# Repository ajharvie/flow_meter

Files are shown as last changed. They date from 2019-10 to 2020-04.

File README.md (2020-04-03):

**Optical Determination of Flow-rate and Flow-Uniformity in Segmented Flows**

This repository contains firmware and design files required to implement a flow meter described in Chemical Engineering Journal. 

The paper can be found here: https://doi.org/10.1016/j.cej.2020.124908

The paper's supporting information contains intructions on assembly, programming and calibration.

*Andrew J. Harvie & John C. de Mello*

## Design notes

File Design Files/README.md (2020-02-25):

Design files for various flow meter parts, including:
1) .stl and .step files for the 3D-printed block.
2) Eagle (.brd) format design for PCB used for mounting OPT101s. This design is slightly updated from the version photographed in the paper (it's smaller).
3) Circuit diagram for device and drawing of block dimensions.

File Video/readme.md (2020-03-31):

Videos of the flow meter in action. Extended captions and information on the videos are included in the paper and its supporting information, but in brief:
1) SI1.mp4 shows footage of the flow stream and measured **Q** value vs time for a flow containing two discrete defects, in a segmented flow of (dyed) DCM and water.
2) SI2.mp4 shows similar data to SI1.mp4 but for a constantly disordered flow.
3) SI3.mp4 shows application of the sensor to quality control. The sensor is mounted in a black opaque box to the left, and switches a two-position valve between "discard" and "collect" positions depending on flow uniformity. The model "reaction" is the mixing of blue- and orange-dyed DCM in a segmented flow with water, to make lovely brown-coloured slugs. Deviations from uniformity result in uneven mixing of dyes, and a change in the colour of the resulting slugs.

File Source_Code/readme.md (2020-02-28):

Source code for the flow meter. Three versions are provided:
1) Flow_Meter_Deprecated.ino is the version used to generate the data shown in the paper, using a teensy 3.6. It is written for a now-obsolete version of teensyduino (v1.39) and should not be used.
2) FlowMeterUPDATED.ino is updated for the current (Feb 2020) version of teensyduino (v1.51). There are a few changes, specifically removal of a few functions related to the ADC library. All settings are otherwise the same. It is compatible with both Teensy 3.6 and 4.0.
3) FlowMeterHighRate.ino is updated for the capability of the new Teensy 4.0 board - the sample rate has been increased 10x, and the number of samples considered in the calculation has been increased 2.5x. This allows for accurate measurement of much higher flow rates. It will not work correctly on the Teensy 3.6.

The file "FlowMeterSignals.ino" contains code for reading the raw optical signals from the flow meter's detectors.

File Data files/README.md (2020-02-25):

Raw data for plots shown in paper.

"Calibration_Data.csv" contains raw signals used to produce figure 5.

"QC_data.csv" contains data recorded during acquisition of video S3 (not shown in paper)

"Q_traces.csv" contains the raw data plotted in figs 6 & 7.

"Ramping_Data.csv" contains the data plotted in fig 9. 

"Signals.csv" contains raw optical signals in figures 3 & 4. 

"TubesPhotograph.png" is a (white balance corrected) photograph of three tubes, which was cropped to obtain the images in figures 10d and 10f. The left-most tube is the result of a control experiment where no xanthate was added, and was not included in the paper's results. The middle and right-hand tubes are shown in figures 10d and 10f respectively.

"DropletImagesBlue.jpg" is the (blue channel monochrome) image from which figures 10c and 10e were cropped, where "DropletImageRaw.jpg" contains the unprocessed raw images (presented as a mosaic in one file).

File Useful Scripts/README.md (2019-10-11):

Some MATLAB scripts used for producing plots, and simulating the flow meter. 
1) "DFT_Signals_Fig4.m", was used to produce figure 4 in the main paper. 
2) "FFT_vs_SDFT.m" produces figure S1. It requires "sdft_plug.m" to work. 
3) "Signal_Generator.m" was used to produce the simulated signals from the supporting information.
4) "Simulator.m" does what it says on the tin - use the signals generated with "Signal_Generator.m". The first 1500 output samples (consistent with the first 15s, or the first full sDFT window) are not output, as these are related to the initial "filling" of the sDFT.

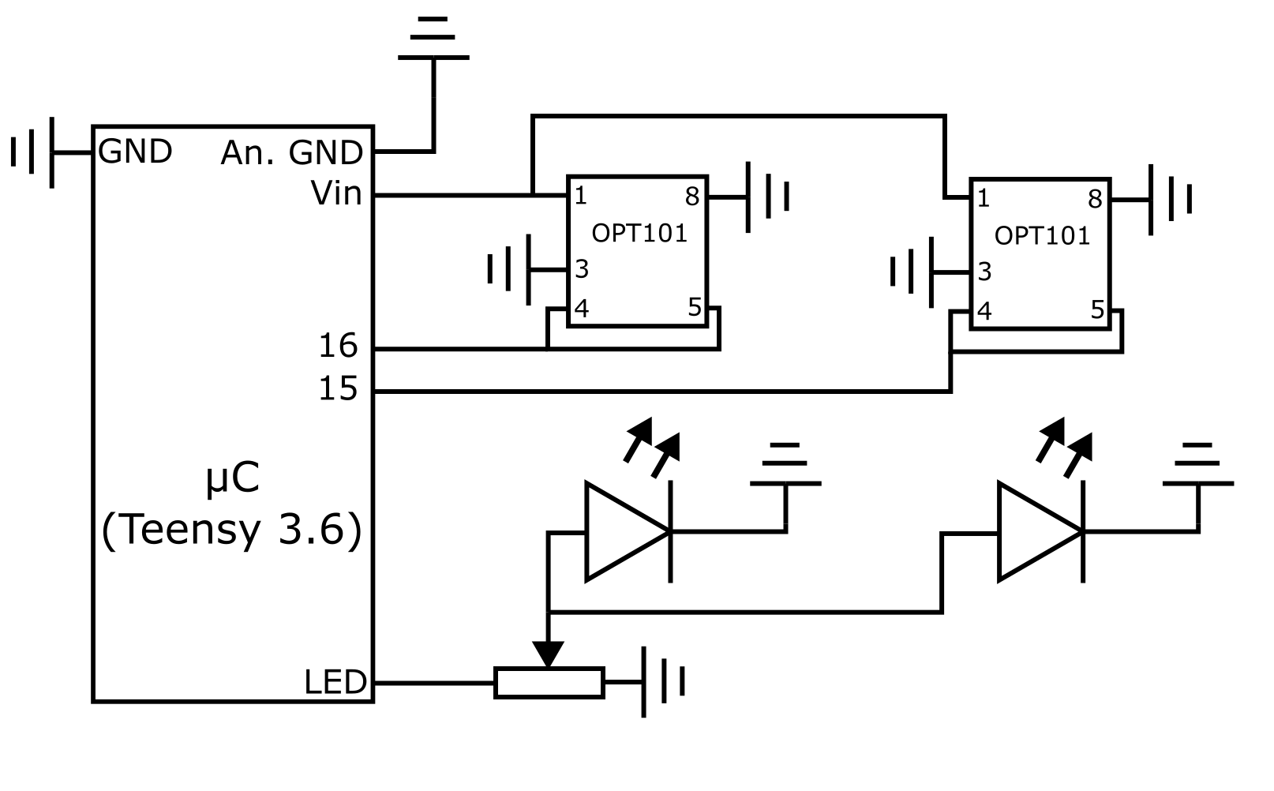
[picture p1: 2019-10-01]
Design Files/circuit_diagram.png

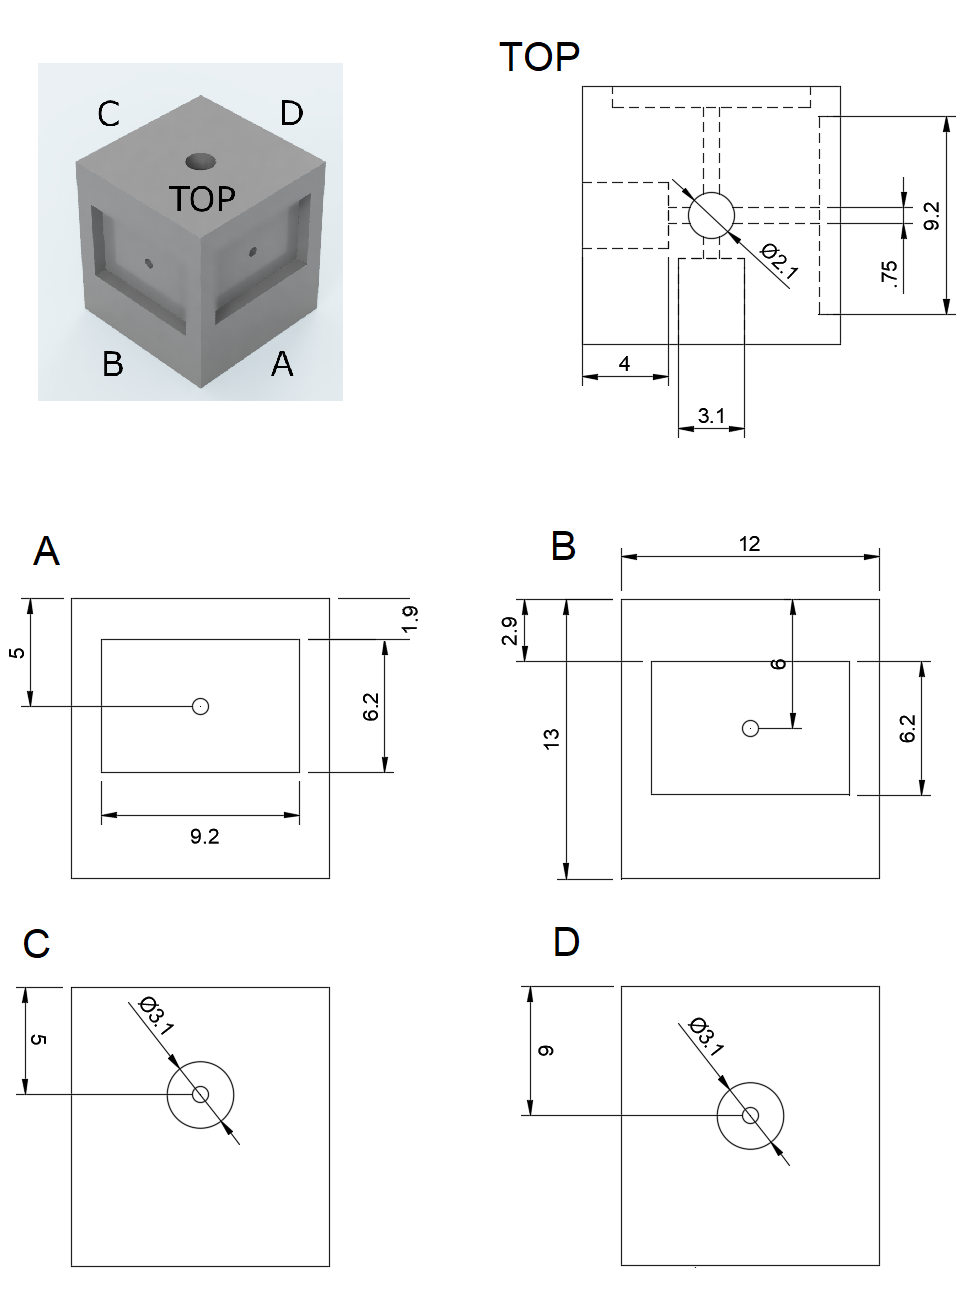
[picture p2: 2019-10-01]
Design Files/technical_drawing.png

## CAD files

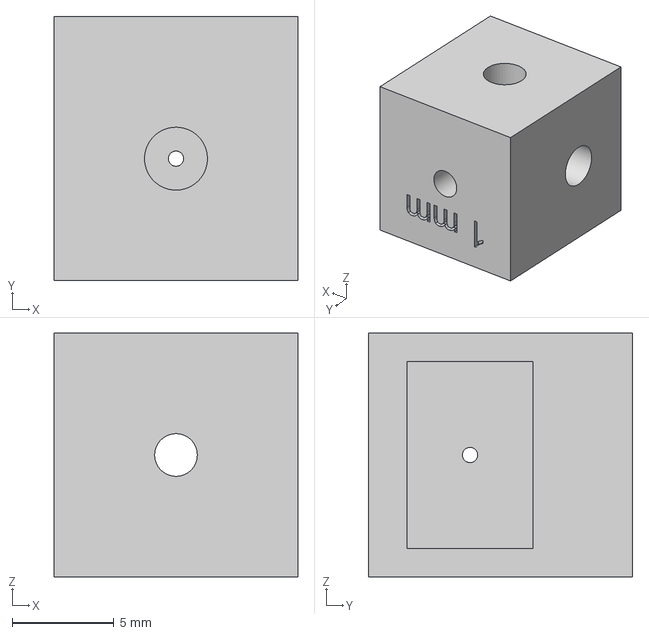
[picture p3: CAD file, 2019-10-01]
Design Files/LED_block_1mm.step
12.0 x 13.0 x 12.0 mm

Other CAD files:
Design Files/LED_block_1mm.stl

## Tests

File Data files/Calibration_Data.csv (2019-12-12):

time | 100 | F | v | Q | 50 | F | v | Q | 15 |  |  |  | 25 | F | v | Q | 300 | F | v | Q | 600 | F | v | Q | 800 | F | v | Q | 1000 | F | v | Q
0 |  | 104.17 | 2.1976 | -0.021 |  | 50 | 1.0549 | 0.0018 |  | 15.07 | 0.3178 | -0.0223 |  | 26.06 | 0.5497 | 0.1012 |  | 304.44 | 6.4227 | -0.001 |  | 616.47 | 13.0057 | 0.003 |  | 803.29 | 16.9471 | -0.0067 |  | 1014.5 | 21.403 | -0.005
1.5 |  | 104.62 | 2.2073 | -0.0056 |  | 50.55 | 1.0664 | 0.0066 |  | 14.44 | 0.3047 | 0.0134 |  | 27.02 | 0.5701 | 0.0569 |  | 304.31 | 6.42 | 0.0167 |  | 616.9 | 13.0147 | 0.0093 |  | 806.02 | 17.0046 | 0.0005 |  | 1011.78 | 21.3456 | 0.0031
3 |  | 104.8 | 2.2109 | 0.0012 |  | 50.68 | 1.0693 | 0.0026 |  | 14.44 | 0.3047 | -0.0123 |  | 27.46 | 0.5794 | -0.037 |  | 304.97 | 6.4339 | 0.0222 |  | 617.97 | 13.0374 | 0.0059 |  | 805.92 | 17.0025 | 0.0084 |  | 1007.79 | 21.2613 | 0.0078
4.5 |  | 103.76 | 2.1891 | 0.0031 |  | 50.39 | 1.0631 | -0.0043 |  | 15.95 | 0.3366 | -0.0842 |  | 27.69 | 0.5842 | 0.0158 |  | 307.64 | 6.4902 | 0.0183 |  | 619.5 | 13.0696 | -0.004 |  | 806.76 | 17.0203 | 0.01 |  | 1006.18 | 21.2274 | 0.0095
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

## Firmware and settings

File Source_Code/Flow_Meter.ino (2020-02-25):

/*
MIT License

Copyright (c) 2020 Andrew Harvie

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
THE SOFTWARE IS PROVIDED "AS IS", WITHOUT WARRANTY OF ANY KIND, EXPRESS OR
IMPLIED, INCLUDING BUT NOT LIMITED TO THE WARRANTIES OF MERCHANTABILITY,
FITNESS FOR A PARTICULAR PURPOSE AND NONINFRINGEMENT. IN NO EVENT SHALL THE
AUTHORS OR COPYRIGHT HOLDERS BE LIABLE FOR ANY CLAIM, DAMAGES OR OTHER
LIABILITY, WHETHER IN AN ACTION OF CONTRACT, TORT OR OTHERWISE, ARISING FROM,
OUT OF OR IN CONNECTION WITH THE SOFTWARE OR THE USE OR OTHER DEALINGS IN THE
SOFTWARE.
*/

#include <ADC.h>
#include "sliding_dft.h"
#define APin A1 //pin for A sensor
#define BPin A2 //pin for B sensor
#define discardPin 14 //connect to discard valve if using
#define ledPin 13
#define pi 3.141592654 //something to do with circles


//Variables
//Timing

int looptime = 10000; //in micros

int current_time = 0;
int old_time = 0;
int gap = 0;
bool wait = true;

//Speed calculation
float corr[200];
float bigCorr = 0;
int peakLocation;
float phase0;
float phase1;
float phaseGap;

//Stability heuristic calculation
float accVar = 0.05; //unstable with Q above this value
int sampleCheck = 150; //number of samples to wait between comparisons

float corrSum = 0; // I
float corrSumOld = 0; // Check with value from sampleCheck samples ago
int stabCheckCount = 0;
float stabValue;

//Output
float gapVolume = 0.785; //volume between detectors in ul. (~0.785 for 1 mm ID) 

float freqSpace;
float flowSpeed;
float flowRate;
float timeDelay;

//Interpolation
float peakLeft;
float peakCentre;
float peakRight;
float delta;
float preciseFreq;

float gapCentre;
float gapLeft;
float gapRight;

//Discarding waste
int stableWait = 0;
int stableThreshold = 4; //number of "stable" samples required before collecting again

//ADC object
ADC *adc = new ADC();

//Two DFT objects 
static SlidingDFT<float, 1500> dft0;
static SlidingDFT<float, 1500> dft1;

void setup() {
  adc->setResolution(12,0);
  adc->setResolution(12,1);
  //sampling speed
  adc->setSamplingSpeed(ADC_SAMPLING_SPEED::VERY_LOW_SPEED, 0);
  adc->setSamplingSpeed(ADC_SAMPLING_SPEED::VERY_LOW_SPEED, 1);
  pinMode(ledPin, OUTPUT); 
  pinMode(discardPin, OUTPUT);
  // serial port for monitoring
  Serial.begin(9600);
  digitalWrite(ledPin, HIGH);
  

  freqSpace = 100.0/1500.0;
}

void loop() {

  //wait between samples
  while(wait == true){
    current_time = micros();
    gap = current_time - old_time;
    if (gap > looptime){
      old_time = current_time;      
      wait = false;
      break;
    }
  }

  // read sensors and update sDFTS
  ADC::Sync_result result = adc->analogSyncRead(APin, BPin);

  int value0 = result.result_adc0; 
  int value1 = result.result_adc1; 

  dft0.update(value0);
  dft1.update(value1);

  //Find common peak by correlating sDFTs
  for(int i=2; i<200; ++i){ //first 200 bins
    corr[i] = abs(dft0.dft[i])*abs(dft1.dft[i]);
    corrSum = corrSum + corr[i]; //Sort of integrates DFT
  }
  
  bigCorr = 0; //peak
  for (int i=2; i<200;++i){ //first 200 bins
    if (corr[i] > bigCorr){
      bigCorr = corr[i];
      peakLocation = i;
    }
  }

  //"RMS" values of common DFT peak
  peakLeft = sqrt(corr[peakLocation-1]);
  peakCentre = sqrt(corr[peakLocation]);
  peakRight = sqrt(corr[peakLocation+1]);

  //interpolation of frequency peak

  delta = 2*((peakRight-peakLeft)/(2*peakCentre+peakLeft+peakRight)); //factor of 2 because Hann window

  preciseFreq = freqSpace*(float(peakLocation)+delta);
  
 //Linear phase interpolaton
 if(delta > 0.0){ //max to rhs of peak
    gapCentre = arg(dft1.dft[peakLocation])-arg(dft0.dft[peakLocation]);
    gapRight = arg(dft1.dft[peakLocation + 1])-arg(dft0.dft[peakLocation + 1]);

    if (gapCentre < 0.0){
      gapCentre = gapCentre + 2*pi;
    }
    if (gapRight < 0.0){
      gapRight = gapRight + 2*pi;
    }
  
    phaseGap = gapCentre + delta*(gapRight - gapCentre);

 }
 else{ //to LHS of peak
    gapCentre = arg(dft1.dft[peakLocation])-arg(dft0.dft[peakLocation]);
    gapLeft = arg(dft1.dft[peakLocation - 1])-arg(dft0.dft[peakLocation - 1]);

    if (gapCentre < 0.0){
      gapCentre = gapCentre + 2*pi;
    }
    if (gapLeft < 0.0){
      gapLeft = gapLeft + 2*pi;
    }
  
    phaseGap = gapCentre - delta*(gapLeft - gapCentre);

 }
  
  //Calculate time delays and flow rate
  timeDelay = phaseGap/(2*pi*preciseFreq);
  flowSpeed = 1/timeDelay; // mm/s (assuming distance between detectors is precisely 1 mm)
  
  flowRate = (gapVolume*flowSpeed)*60.0; //factor of 60 for units of minutes^-1

  ++stabCheckCount;
  if (stabCheckCount == sampleCheck){
    stabValue = (corrSum - corrSumOld)/corrSum; //dividing to normalise it
    corrSumOld = corrSum;
    stabCheckCount = 0;
      Serial.print(flowRate); // flow rate (depends on calibration parameter for given tubing/block)
      Serial.print(" ");
      Serial.print(flowSpeed,4); // "Speed" of droplets (in mm/s)
      Serial.print(" ");
      Serial.print(stabValue, 4); // Stability heuristic
      Serial.print(" "); 
      if (stabValue > accVar){
        Serial.println("Discard");
        digitalWrite(discardPin, LOW);
        stableWait = 0;
      }
      else if (stabValue < -1*accVar){
        Serial.println("Discard");
        digitalWrite(discardPin, LOW);
        stableWait = 0;
      }
      else{
        if(stableWait == stableThreshold){
          Serial.println("Keep");
          digitalWrite(discardPin, HIGH);
          //stableWait = 0;
        }
        else{
          Serial.println("Wait");
          ++stableWait;
        }
      }
  }
  
  corrSum = 0; 
  wait = true; 
    
}

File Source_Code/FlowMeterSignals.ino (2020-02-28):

#include <ADC.h>

#define ledPin 13

int current_time = 0;
int old_time = 0;
int gap = 0;
int looptime = 10000;
bool wait = true;

ADC *adc = new ADC();


void setup() {
  pinMode(ledPin, OUTPUT); 
  // serial port for monitoring
  Serial.begin(9600);
  digitalWrite(ledPin, HIGH);
}

void loop() {

  while(wait == true){
    current_time = micros();
    gap = current_time - old_time;
    if (gap > looptime){
      old_time = current_time;      
      wait = false;
      break;
    }
  }
  
  ADC::Sync_result result = adc->analogSyncRead(A1, A2);

  int value0 = result.result_adc0; 
  int value1 = result.result_adc1; 

  Serial.print(value0);
  Serial.print(" ");
  Serial.println(value1);

  wait = true; 
  
}

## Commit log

2019-09-30 Update for readability and reset defaults
    [Flow_Meter.ino]
2019-10-01 added design files
    [LED_block_1mm.step, LED_block_1mm.stl]
2019-10-10 added board for electrical connection to APDs
    [OPT_101_board.brd]
2019-12-12 added missing 1000 1µl/min data
    [Calibration_Data.csv]
2020-02-25 Data for monitoring of reactive flows (fig10)
    [ReactiveFlowsData.csv]
2020-02-28 add updated flow meter firmware
2020-02-28 Added code optimised for Teensy 4.0
2020-02-28 Added extra firmware options
    Finished adding extra firmware for new versions of teensyduino, and added new code to exploit the capability of the new teensy 4.0 board. This allows measurement of much higher flow rates than before.
2020-02-28 Updated readme
    included correct version numbers for teensyduino software
